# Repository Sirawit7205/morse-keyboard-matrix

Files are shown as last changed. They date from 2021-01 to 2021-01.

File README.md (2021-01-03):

# Morse Keyboard (Matrix Version)
This is a Morse Code Keyboard that's built only with common logic ICs. 

**Note: While I'm trying to follow morse code standard, I did not guaranteed that it will conform to ham radio standards and regulations. Use at your own risk.**

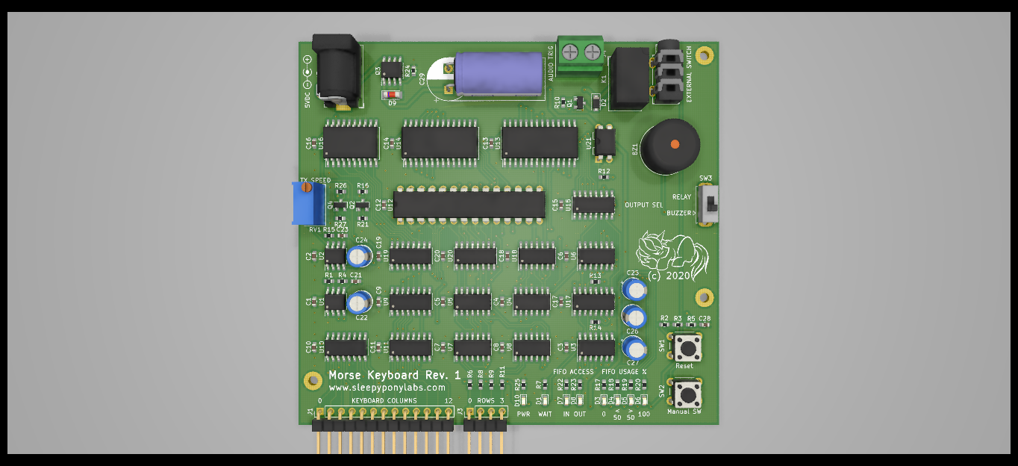
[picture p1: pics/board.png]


## Features

- Outputs full english alphabets, numbers, and 12 control codes.
- Built-In Keyboard Encoder circuit, connects any keypad matrix to the board to get started.
- 512 characters FIFO buffer.
- Manual Switch
- External key connector.
- Output buzzer and relay.

## Licensing

Hardware is licensed under `SPDX-License-Identifier: Apache-2.0 WITH SHL-2.1`

Documentation is licensed under `SPDX-License-Identifier: CC-BY-SA-4.0`

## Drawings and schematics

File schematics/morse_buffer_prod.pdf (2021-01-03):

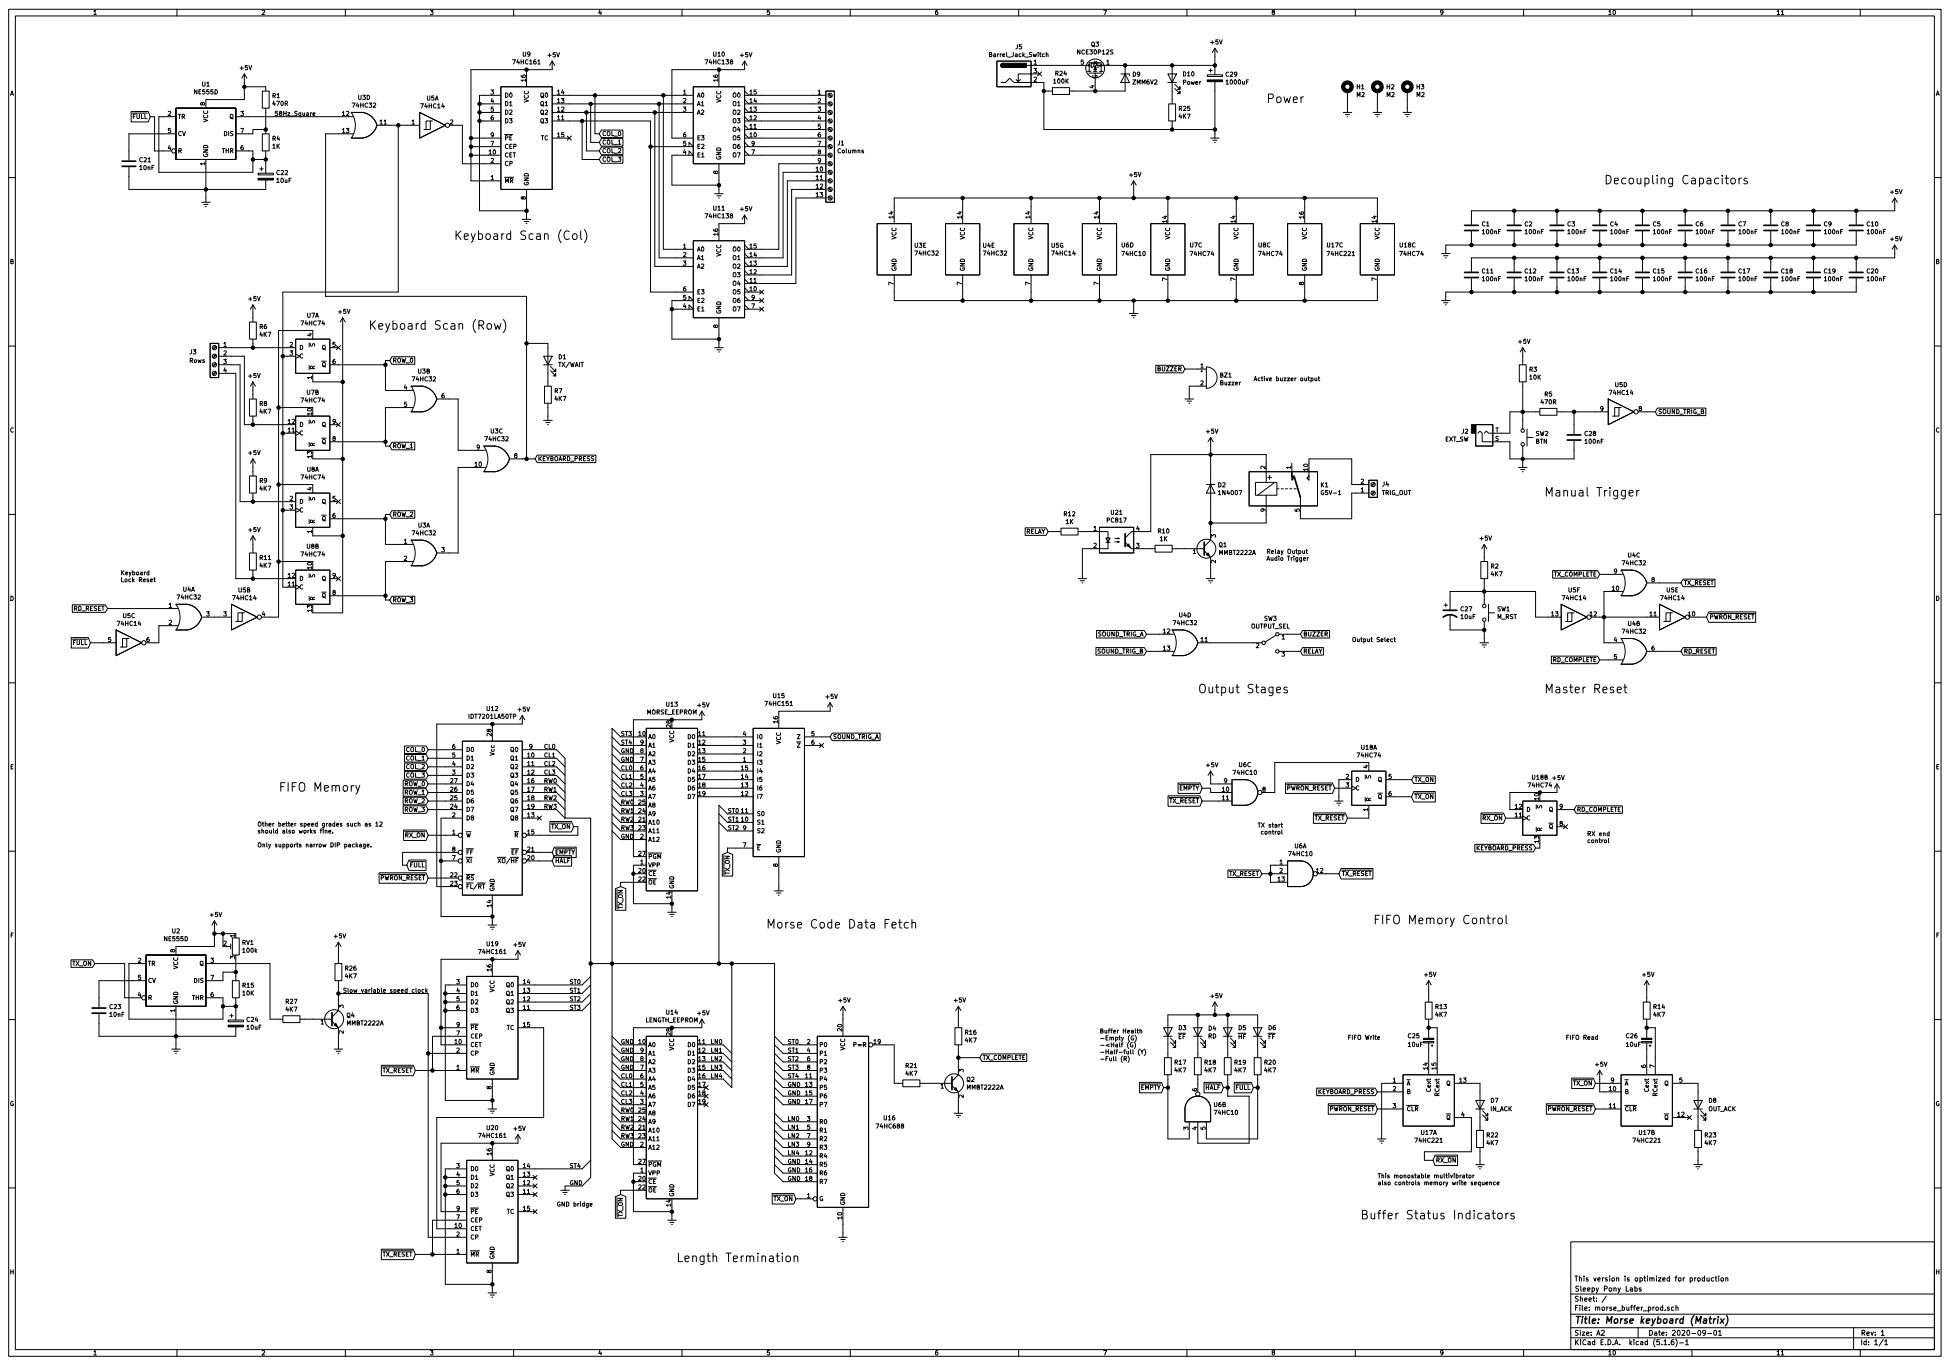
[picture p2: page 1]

Morse Code Data Fetch
LENGTH_EEPROM

This monostable multivibrator also controls memory write sequence

This version is optimized for production
File: morse_buffer_prod.sch Sheet: / Sleepy Pony Labs

Id: 1/1 Title: Morse keyboard (Matrix)

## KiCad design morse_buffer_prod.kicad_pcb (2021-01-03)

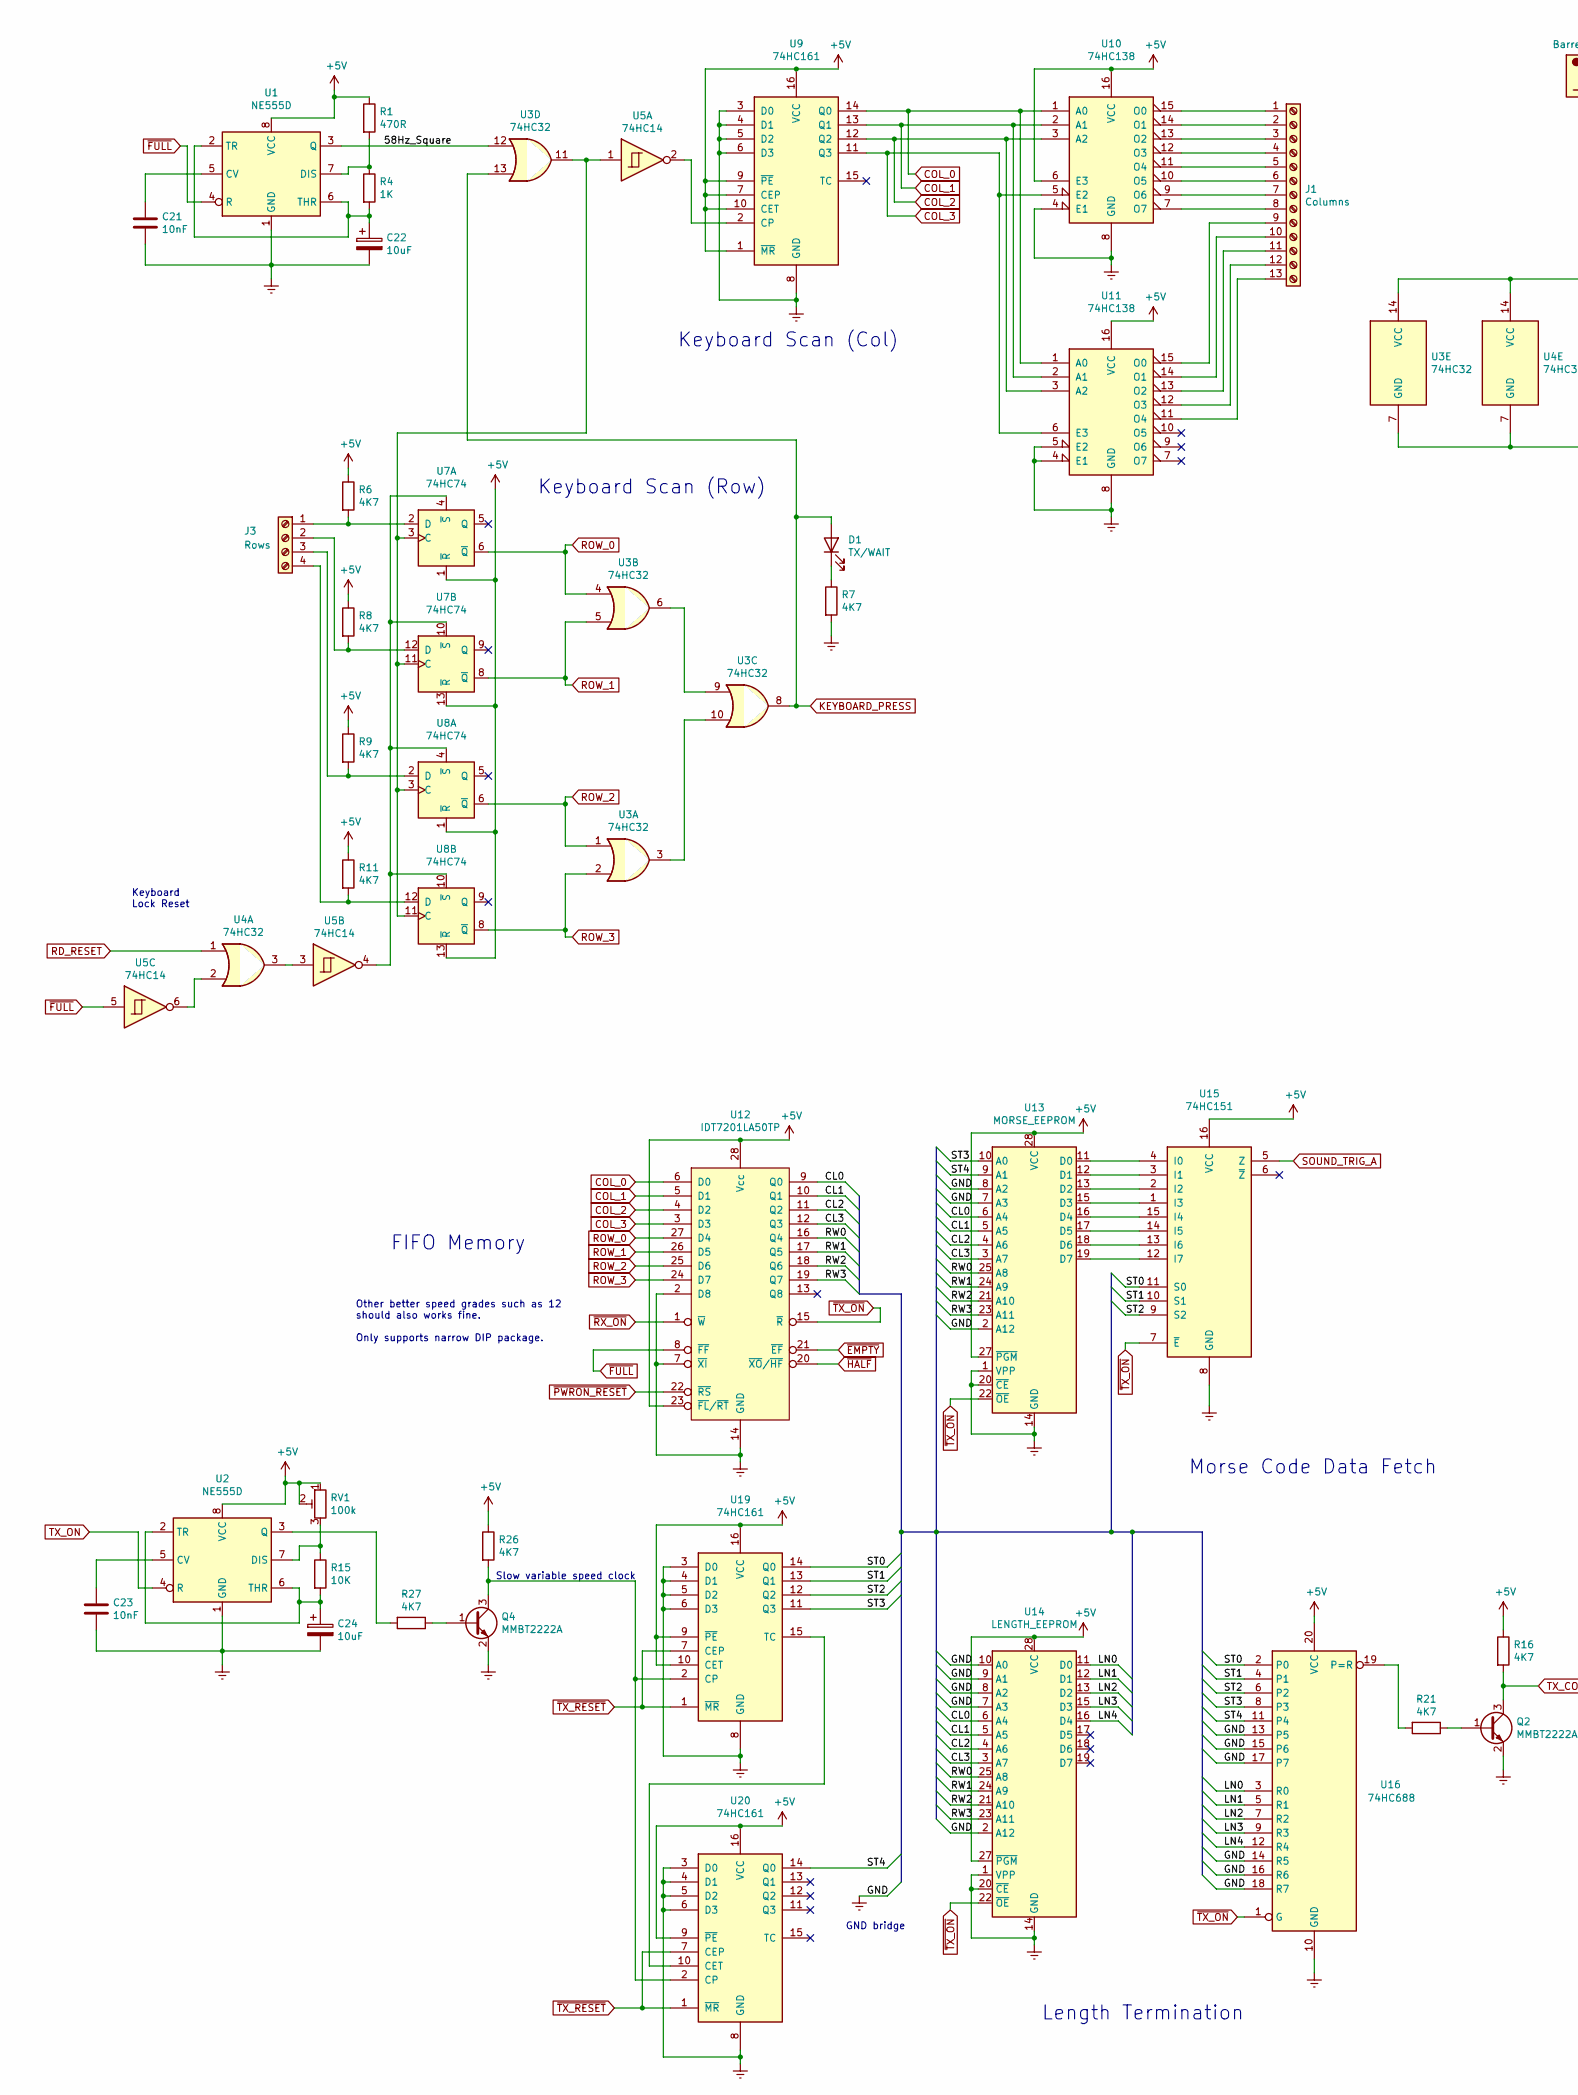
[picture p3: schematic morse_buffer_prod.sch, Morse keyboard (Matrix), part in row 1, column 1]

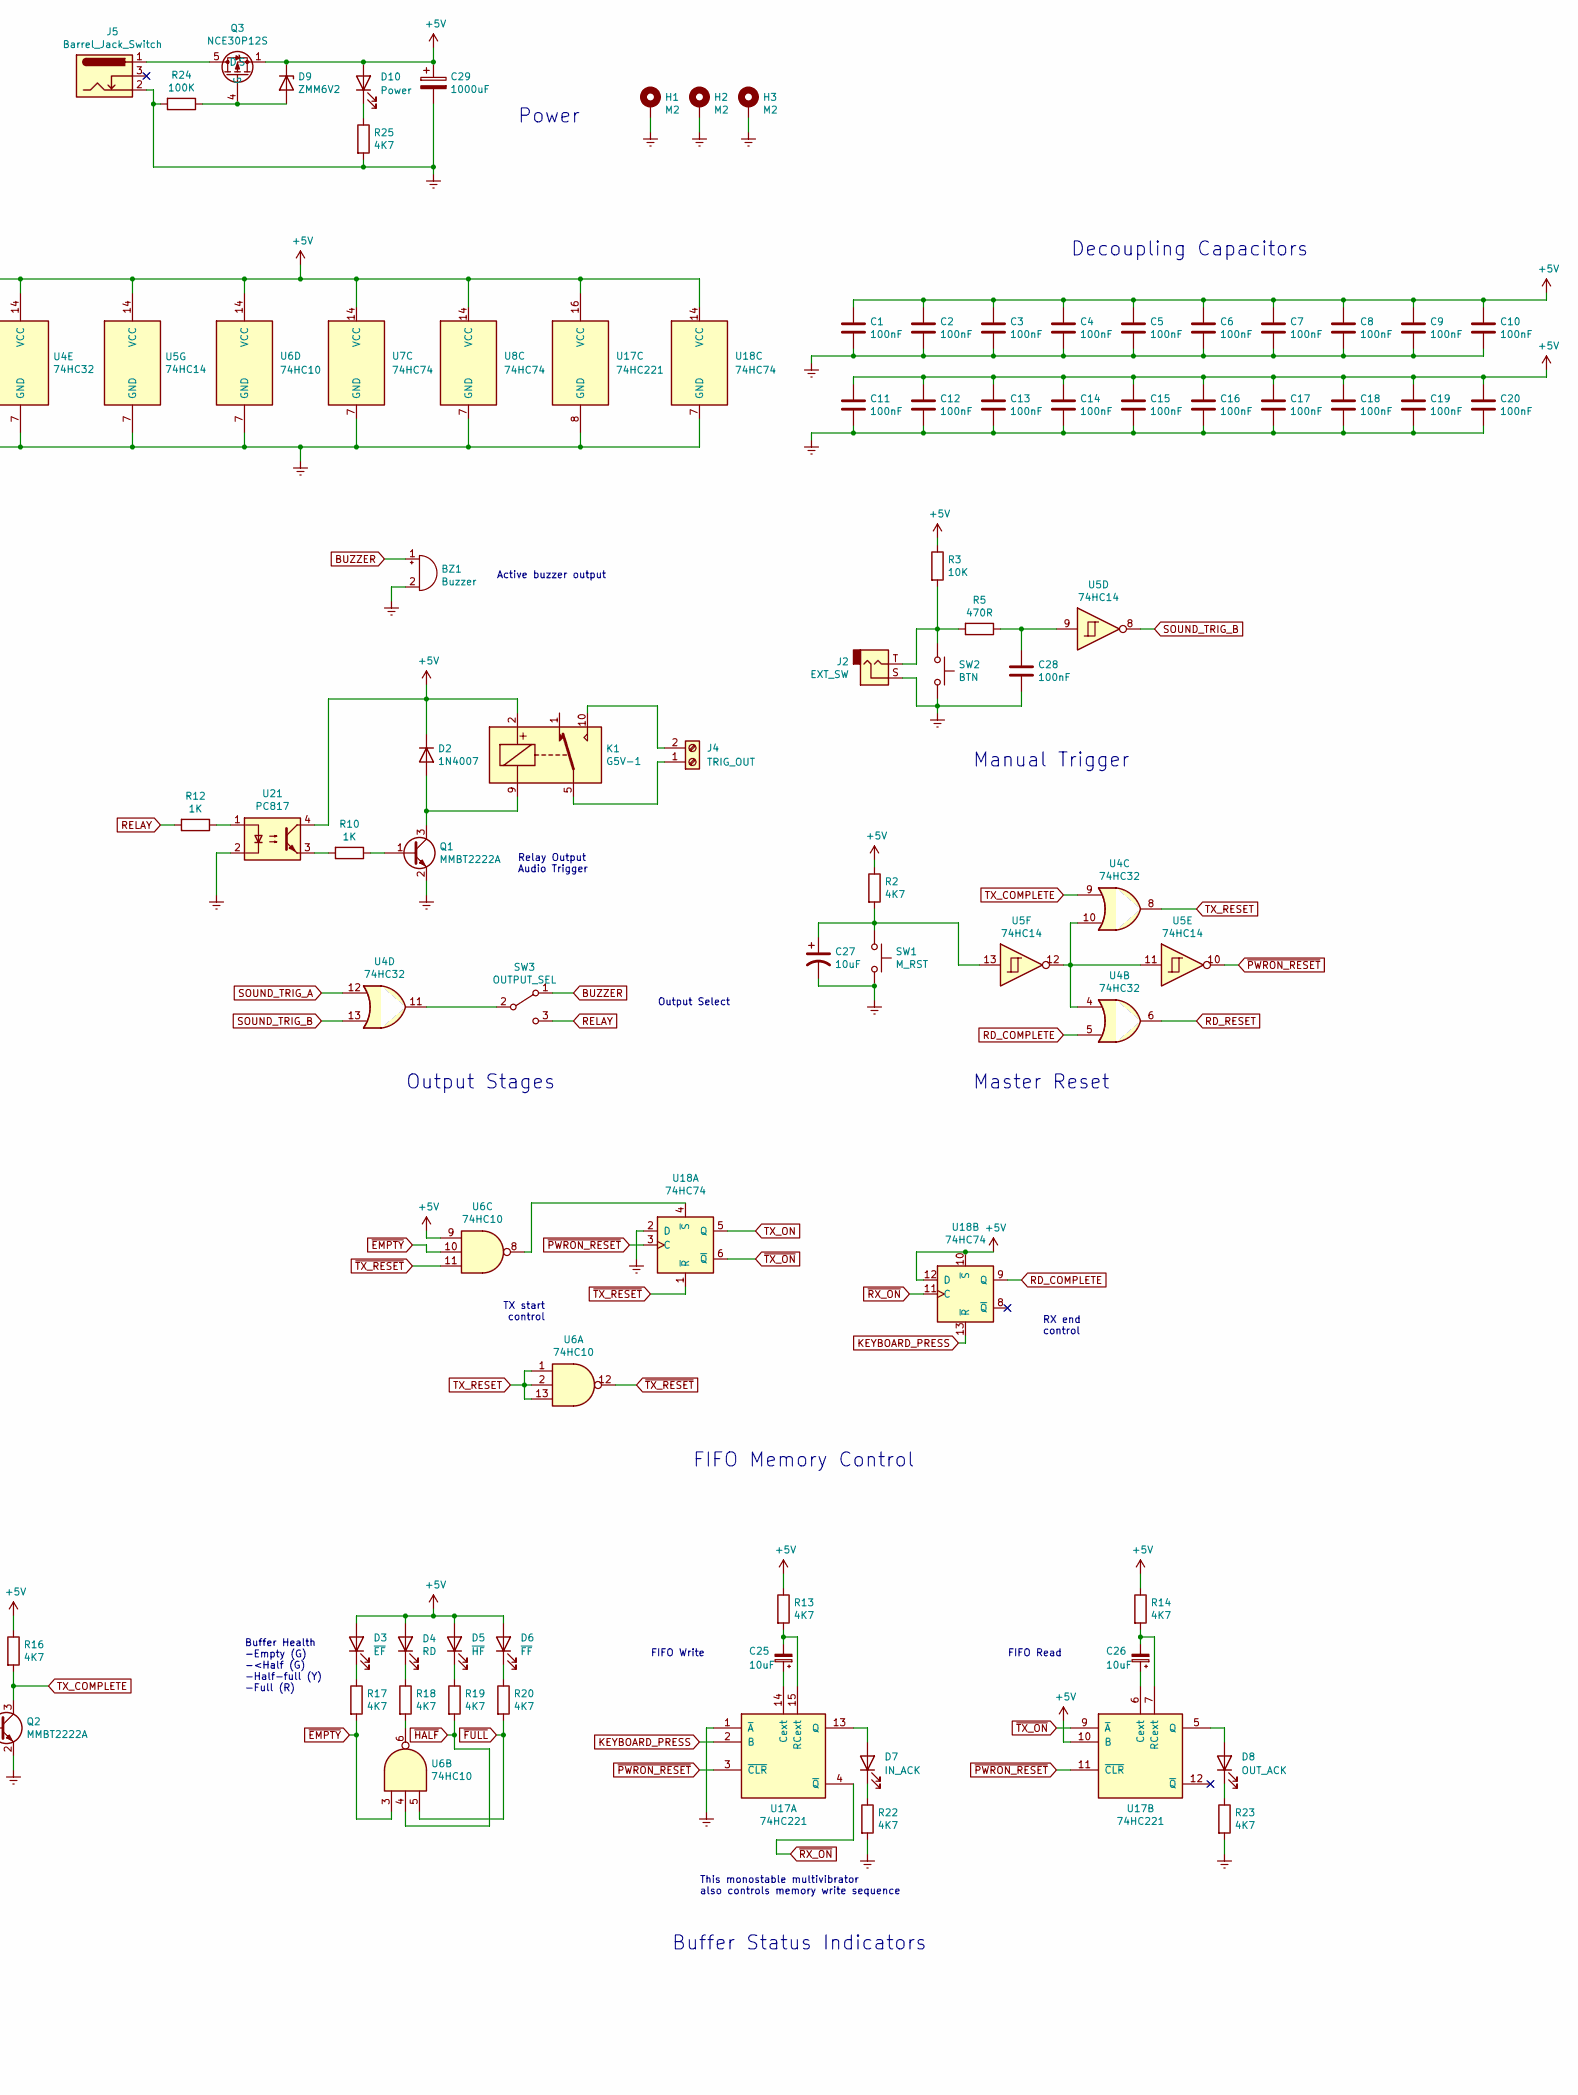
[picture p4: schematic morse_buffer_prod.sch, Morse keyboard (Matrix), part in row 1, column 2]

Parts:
BZ1: Buzzer; Buzzer_12x9.5RM7.6
C1, C2, C3, C4, C5, C6, C7, C8, C9, C10, C11, C12, C13, C14, C15, C16, C17, C18, C19, C20, C28: 100nF; C_0603_1608Metric
C21, C23: 10nF; C_0603_1608Metric
C22, C24, C25, C26, C27: 10uF; CP_Radial_D5.0mm_P2.00mm
C29: 1000uF; CP_Radial_D10.0mm_P5.00mm
D1: TX/WAIT; LED_0603_1608Metric
D2: 1N4007; D_SOD-123F
D3: ~EF; LED_0603_1608Metric
D4: RD; LED_0603_1608Metric
D5: ~HF; LED_0603_1608Metric
D6: ~FF; LED_0603_1608Metric
D7: IN_ACK; LED_0603_1608Metric
D8: OUT_ACK; LED_0603_1608Metric
D9: ZMM6V2; D_MiniMELF
D10: Power; LED_0603_1608Metric
H1, H2, H3: M2; MountingHole_2.2mm_M2_Pad
J1: Columns; PinHeader_1x13_P2.54mm_Vertical
J2: EXT_SW; PJ-313
J3: Rows; PinHeader_1x04_P2.54mm_Vertical
J4: TRIG_OUT; TerminalBlock_bornier-2_P5.08mm
J5: Barrel_Jack_Switch; BarrelJack_Horizontal
K1: G5V-1; Relay_SPDT_Omron_G5V-1
Q1, Q2, Q4: MMBT2222A; SOT-23
Q3: NCE30P12S; SOIC-8_3.9x4.9mm_P1.27mm
R1, R5: 470R; R_0603_1608Metric
R2, R6, R7, R8, R9, R11, R13, R14, R16, R17, R18, R19, R20, R21, R22, R23, R25, R26, R27: 4K7; R_0603_1608Metric
R3, R15: 10K; R_0603_1608Metric
R4, R10, R12: 1K; R_0603_1608Metric
R24: 100K; R_0603_1608Metric
RV1: 100k; Potentiometer_Bourns_3296W_Vertical
SW1: M_RST; SW_PUSH_6mm
SW2: BTN; SW_PUSH_6mm
SW3: OUTPUT_SEL; SW_Slide_1P2T_CK_OS102011MS2Q
U1, U2: NE555D; SOIC-8_3.9x4.9mm_P1.27mm
U3, U4: 74HC32; SOIC-14_3.9x8.7mm_P1.27mm
U5: 74HC14; SOIC-14_3.9x8.7mm_P1.27mm
U6: 74HC10; SOIC-14_3.9x8.7mm_P1.27mm
U7, U8, U18: 74HC74; SOIC-14_3.9x8.7mm_P1.27mm
U9, U19, U20: 74HC161; SOIC-16_3.9x9.9mm_P1.27mm
U10, U11: 74HC138; SOIC-16_3.9x9.9mm_P1.27mm
U12: IDT7201LA50TP; DIP-28_W7.62mm
U13: MORSE_EEPROM; SOIC-28W_7.5x17.9mm_P1.27mm
U14: LENGTH_EEPROM; SOIC-28W_7.5x17.9mm_P1.27mm
U15: 74HC151; SOIC-16_3.9x9.9mm_P1.27mm
U16: 74HC688; SOIC-20W_7.5x12.8mm_P1.27mm
U17: 74HC221; SOIC-16_3.9x9.9mm_P1.27mm
U21: PC817; DIP-4_W7.62mm

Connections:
+5V: C1.1, C2.1, C3.1, C4.1, C5.1, C6.1, C7.1, C8.1, C9.1, C10.1, C11.1, C12.1, C13.1, C14.1, C15.1, C16.1, C17.1, C18.1, C19.1, C20.1, C29.1, D2.1 (K), D3.2 (A), D4.2 (A), D5.2 (A), D6.2 (A), D9.1 (K), D10.2 (A), K1.2, Q3.1 (S), Q3.2 (S), Q3.3 (S), R1.1, R2.1, R3.1, R6.1, R8.1, R9.1, R11.1, R13.1, R14.1, R16.1, R26.1, RV1.1, RV1.2, U1.8 (VCC), U2.8 (VCC), U3.14 (VCC), U4.14 (VCC), U5.14 (VCC), U6.9, U6.14 (VCC), U7.1 (~R), U7.13 (~R), U7.14 (VCC), U8.1 (~R), U8.13 (~R), U8.14 (VCC), U9.1 (~MR), U9.7 (CEP), U9.9 (~PE), U9.10 (CET), U9.16 (VCC), U10.6 (E3), U10.16 (VCC), U11.16 (VCC), U12.23 (~FL~/~RT), U12.28 (Vcc), U13.27 (~PGM), U13.28 (VCC), U14.27 (~PGM), U14.28 (VCC), U15.16 (VCC), U16.20 (VCC), U17.10 (B), U17.16 (VCC), U18.10 (~S), U18.12 (D), U18.14 (VCC), U19.9 (~PE), U19.10 (CET), U19.16 (VCC), U20.9 (~PE), U20.16 (VCC), U21.4
/58Hz_Square: U1.3 (Q), U3.12
/CL0: U12.9 (Q0), U13.6 (A4), U14.6 (A4)
/CL1: U12.10 (Q1), U13.5 (A5), U14.5 (A5)
/CL2: U12.11 (Q2), U13.4 (A6), U14.4 (A6)
/CL3: U12.12 (Q3), U13.3 (A7), U14.3 (A7)
/LN0: U14.11 (D0), U16.3 (R0)
/LN1: U14.12 (D1), U16.5 (R1)
/LN2: U14.13 (D2), U16.7 (R2)
/LN3: U14.15 (D3), U16.9 (R3)
/LN4: U14.16 (D4), U16.12 (R4)
/RW0: U12.16 (Q4), U13.25 (A8), U14.25 (A8)
/RW1: U12.17 (Q5), U13.24 (A9), U14.24 (A9)
/RW2: U12.18 (Q6), U13.21 (A10), U14.21 (A10)
/RW3: U12.19 (Q7), U13.23 (A11), U14.23 (A11)
/ST0: U15.11 (S0), U16.2 (P0), U19.14 (Q0)
/ST1: U15.10 (S1), U16.4 (P1), U19.13 (Q1)
/ST2: U15.9 (S2), U16.6 (P2), U19.12 (Q2)
/ST3: U13.10 (A0), U16.8 (P3), U19.11 (Q3)
/ST4: U13.9 (A1), U16.11 (P4), U20.14 (Q0)
BUZZER: BZ1.1 (-), SW3.1 (A)
COL_0: U9.14 (Q0), U10.1 (A0), U11.1 (A0), U12.6 (D0)
COL_1: U9.13 (Q1), U10.2 (A1), U11.2 (A1), U12.5 (D1)
COL_2: U9.12 (Q2), U10.3 (A2), U11.3 (A2), U12.4 (D2)
COL_3: U9.11 (Q3), U10.5 (E2), U11.6 (E3), U12.3 (D3)
GNDREF: BZ1.2 (+), C1.2, C2.2, C3.2, C4.2, C5.2, C6.2, C7.2, C8.2, C9.2, C10.2, C11.2, C12.2, C13.2, C14.2, C15.2, C16.2, C17.2, C18.2, C19.2, C20.2, C21.2, C22.2, C23.2, C24.2, C27.2, C28.2, C29.2, H1.1, H2.1, H3.1, J2.S, J5.2, Q1.2 (E), Q2.2 (E), Q4.2 (E), R7.2, R22.2, R23.2, R24.2, R25.2, SW1.2, SW2.2, U1.1 (GND), U2.1 (GND), U3.7 (GND), U4.7 (GND), U5.7 (GND), U6.7 (GND), U7.7 (GND), U8.7 (GND), U9.3 (D0), U9.4 (D1), U9.5 (D2), U9.6 (D3), U9.8 (GND), U10.4 (E1), U10.8 (GND), U11.4 (E1), U11.5 (E2), U11.8 (GND), U12.2 (D8), U12.7 (~XI), U12.14 (GND), U13.1 (VPP), U13.2 (A12), U13.7 (A3), U13.8 (A2), U13.14 (GND), U13.20 (~CE), U14.1 (VPP), U14.2 (A12), U14.7 (A3), U14.8 (A2), U14.9 (A1), U14.10 (A0), U14.14 (GND), U14.20 (~CE), U15.8 (GND), U16.10 (GND), U16.13 (P5), U16.14 (R5), U16.15 (P6), U16.16 (R6), U16.17 (P7), U16.18 (R7), U17.1 (~A), U17.8 (GND), U18.2 (D), U18.7 (GND), U19.3 (D0), U19.4 (D1), U19.5 (D2), U19.6 (D3), U19.8 (GND), U20.3 (D0), U20.4 (D1), U20.5 (D2), U20.6 (D3), U20.8 (GND), U21.2
KEYBOARD_PRESS: D1.2 (A), U3.8, U3.13, U17.2 (B), U18.13 (~R)
unnamed: C21.1, U1.5 (CV)
unnamed: C22.1, R4.2, U1.2 (TR), U1.6 (THR)
unnamed: C23.1, U2.5 (CV)
unnamed: C24.1, R15.2, U2.2 (TR), U2.6 (THR)
unnamed: C25.1, U17.14 (Cext)
unnamed: C25.2, R13.2, U17.15 (RCext)
unnamed: C26.1, U17.6 (Cext)
unnamed: C26.2, R14.2, U17.7 (RCext)
unnamed: C27.1, R2.2, SW1.1, U5.13
unnamed: C28.1, R5.1, U5.9
unnamed: D1.1 (K), R7.1
unnamed: D2.2 (A), K1.9, Q1.3 (C)
unnamed: D3.1 (K), R17.1
unnamed: D4.1 (K), R18.1
unnamed: D5.1 (K), R19.1
unnamed: D6.1 (K), R20.1
unnamed: D7.1 (K), R22.1
unnamed: D7.2 (A), U17.13 (Q)
unnamed: D8.1 (K), R23.1
unnamed: D8.2 (A), U17.5 (Q)
unnamed: D9.2 (A), Q3.4 (G), R24.1
unnamed: D10.1 (K), R25.1
unnamed: J1.1, U10.15 (O0)
unnamed: J1.2, U10.14 (O1)
unnamed: J1.3, U10.13 (O2)
unnamed: J1.4, U10.12 (O3)
unnamed: J1.5, U10.11 (O4)
unnamed: J1.6, U10.10 (O5)
unnamed: J1.7, U10.9 (O6)
unnamed: J1.8, U10.7 (O7)
unnamed: J1.9, U11.15 (O0)
unnamed: J1.10, U11.14 (O1)
unnamed: J1.11, U11.13 (O2)
unnamed: J1.12, U11.12 (O3)
unnamed: J1.13, U11.11 (O4)
unnamed: J2.T, R3.2, R5.2, SW2.1
unnamed: J3.1, R6.2, U7.2 (D)
unnamed: J3.2, R8.2, U7.12 (D)
unnamed: J3.3, R9.2, U8.2 (D)
unnamed: J3.4, R11.2, U8.12 (D)
unnamed: J4.1, K1.5, K1.6
unnamed: J4.2, K1.10
unnamed: J5.1, Q3.5 (D), Q3.6 (D), Q3.7 (D), Q3.8 (D)
unnamed: Q1.1 (B), R10.1
unnamed: Q2.1 (B), R21.1
unnamed: Q4.1 (B), R27.1
unnamed: Q4.3 (C), R26.2, U19.2 (CP), U20.2 (CP)
unnamed: R1.2, R4.1, U1.7 (DIS)
unnamed: R10.2, U21.3
unnamed: R12.1, U21.1
unnamed: R15.1, RV1.3, U2.7 (DIS)
unnamed: R18.2, U6.6
unnamed: R21.2, U16.19 (P=R)
unnamed: R27.2, U2.3 (Q)
unnamed: SW3.2 (B), U4.11
unnamed: U3.6, U3.9
unnamed: U3.3, U3.10
unnamed: U3.11, U5.1, U7.3 (C), U7.11 (C), U8.3 (C), U8.11 (C)
unnamed: U4.2, U5.6
unnamed: U4.3, U5.3
unnamed: U4.4, U4.10, U5.11, U5.12
unnamed: U5.2, U9.2 (CP)
unnamed: U5.4, U7.4 (~S), U7.10 (~S), U8.4 (~S), U8.10 (~S)
unnamed: U13.11 (D0), U15.4 (I0)
unnamed: U13.12 (D1), U15.3 (I1)
unnamed: U13.13 (D2), U15.2 (I2)
unnamed: U13.15 (D3), U15.1 (I3)
unnamed: U13.16 (D4), U15.15 (I4)
unnamed: U13.17 (D5), U15.14 (I5)
unnamed: U13.18 (D6), U15.13 (I6)
unnamed: U13.19 (D7), U15.12 (I7)
unnamed: U6.8, U18.4 (~S)
unnamed: U19.15 (TC), U20.10 (CET)
RD_COMPLETE: U4.5, U18.9 (Q)
RD_RESET: U4.1, U4.6
RELAY: R12.2, SW3.3 (C)
ROW_0: U3.4, U7.6 (~Q), U12.27 (D4)
ROW_1: U3.5, U7.8 (~Q), U12.26 (D5)
ROW_2: U3.1, U8.6 (~Q), U12.25 (D6)
ROW_3: U3.2, U8.8 (~Q), U12.24 (D7)
SOUND_TRIG_A: U4.12, U15.5 (Z)
SOUND_TRIG_B: U4.13, U5.8
TX_COMPLETE: Q2.3 (C), R16.2, U4.9
TX_ON: U2.4 (R), U18.5 (Q)
TX_RESET: U4.8, U6.1, U6.2, U6.13
~EMPTY: R17.2, U6.3, U6.10, U12.21 (~EF)
~FULL: R20.2, U1.4 (R), U5.5, U6.5, U12.8 (~FF)
~HALF: R19.2, U6.4, U12.20 (~XO~/~HF)
~PWRON_RESET: U5.10, U12.22 (~RS), U17.3 (~CLR), U17.11 (~CLR), U18.3 (C)
~RX_ON: U12.1 (~W), U17.4 (~Q), U18.11 (C)
~TX_ON: U12.15 (~R), U13.22 (~OE), U14.22 (~OE), U15.7 (~E), U16.1 (G), U17.9 (~A), U18.6 (~Q)
~TX_RESET: U6.11, U6.12, U18.1 (~R), U19.1 (~MR), U19.7 (CEP), U20.1 (~MR), U20.7 (CEP)

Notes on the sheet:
Manual Trigger
Keyboard Scan (Row)
Relay Output Audio Trigger
Output Select
Active buzzer output
Morse Code Data Fetch
Keyboard Scan (Col)
Length Termination
TX start control
FIFO Memory Control
FIFO Read
FIFO Write
Buffer Status Indicators
Buffer Health -Empty (G) -<Half (G) -Half-full (Y) -Full (R)
This monostable multivibrator also controls memory write sequence
RX end control
FIFO Memory
Keyboard Lock Reset
Other better speed grades such as 12 should also works fine. Only supports narrow DIP package.
Master Reset
Slow variable speed clock
Output Stages
Power
Decoupling Capacitors
GND bridge

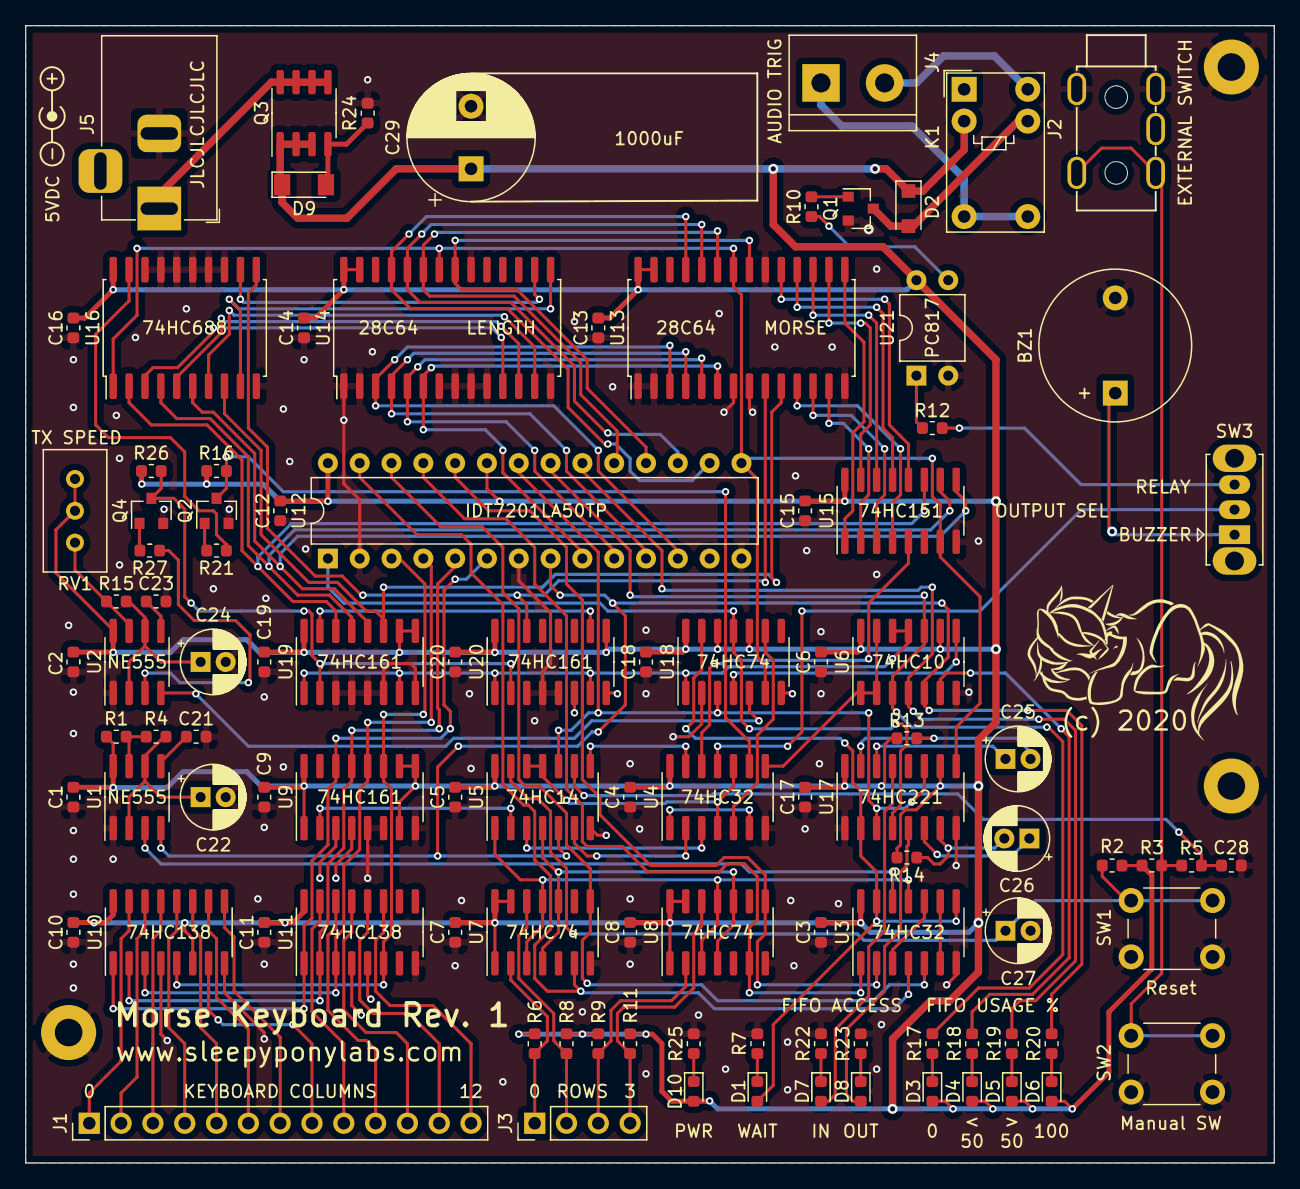
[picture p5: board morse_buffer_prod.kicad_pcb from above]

Board: 2 copper layers, 99.7 x 90.8 mm, 105 parts (0 on the bottom side), 119 nets.

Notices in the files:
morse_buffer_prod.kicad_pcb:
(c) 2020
